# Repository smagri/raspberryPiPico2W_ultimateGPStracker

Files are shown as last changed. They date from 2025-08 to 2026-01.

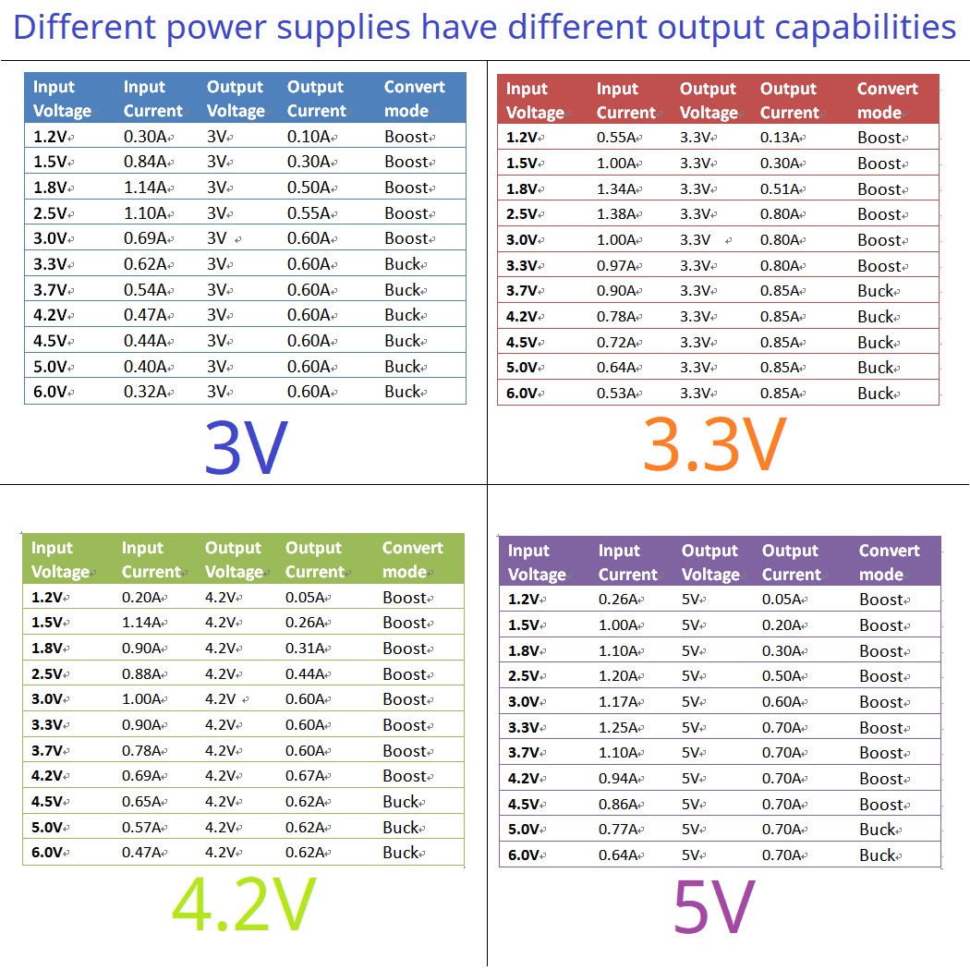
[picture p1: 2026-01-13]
images/ND0603PCbuckBoostSpecs.jpg

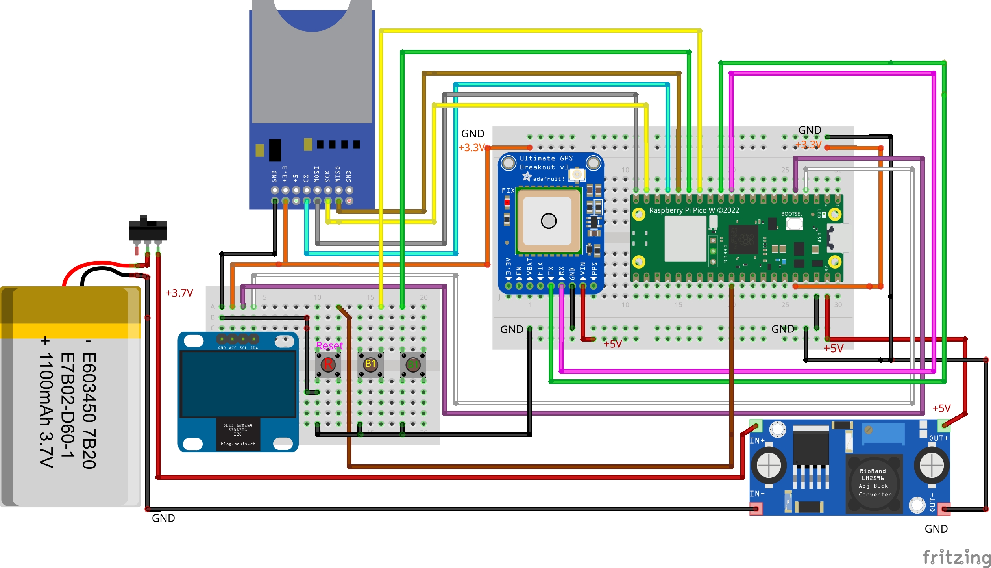
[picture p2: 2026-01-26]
images/circuitDiagram.fzz.3.jpg

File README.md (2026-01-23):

Project started 19jul2025.

This  project follows  Paul McWhorter  youtube videos  to build  a GPS
tracker with the Rasberry Pi Pico W.  However, I have used the Pi Pico
2 W and everything works well.   Note also that all .pdf documents are
in  ~/proj/paulMcWhorter/docs/ultimateGPStracker also,  but links  are
given below.

Bill of materials:
-----------------
Raspberry Pi Pico W: 
https://amzn.to/3FA4tqS

Adafruit Ultimate GPS version 3:
https://amzn.to/4jeRIjj

External Antenna (OPTIONAL) I would highly recommend this: 
https://amzn.to/4myFWTL

Button Battery For Quicker Fix: 
https://amzn.to/3FjoUbH

Breadvolt Power  Supply (OPTIONAL) I  would highly recommend  this for
when your project is finished:
https://amzn.to/4kuuJ50

Charging Cable (If You Don’t Have): 
https://amzn.to/3Z0EMGF

OLED SSD1306: 
https://amzn.to/43tFYUk

Soldering Iron: 
https://amzn.to/3HpZolw

Solder Practice Components:
https://amzn.to/4mNaEca

Extra Solder: 
https://amzn.to/4kuuDdE

Safety Glasses: 
https://amzn.to/4mwGMjR

Breadboard and Wires (If You Don’t Have): 
https://amzn.to/4kggv86

Hard boot of raspberry pi pico 2
--------------------------------

Hard boot, all hardware is reset:

Connect pin30==RUN momentarily to ground.  Any main.py in flash memory
starts executing immediately.

Or plug and unplug the USB cable.

Programming the raspberry Pi Pico 2:
-----------------------------------

Raspberry Pi Pico 2 W with RP2350, is the correct firmware file from:
https://www.raspberrypi.com/documentation/microcontrollers/micropython.html
mp_firmware_unofficial_latest.uf2

To flash firmware,  hold down bootsel button while  plugging in power,
then copy  .uf2 to  RP2350 mass  storage device  that appears  on your
computer.  If correctly flashed the  mass storage drive will dissapear
from your computer directory.

ls /dev/ttyACM0  should now  appear, so  select it  in thonny  and you
should get the miropython prompt.

Test with:
print("hello").

Why  use thonny  editor as  the default  editor for  rasberry pi  pico
-------------------------------------------------------------------------
projects:  I  use  emacs  for  editing  and  thonny  for  running  the
-------------------------------------------------------------------------
micropython scripts.
-------------------------------------------------------------------------

1.  Beginner-Friendly  Design:  Thonny is  specifically  designed  for
beginners in programming, especially  for Python. Its clean interface,
built-in debugger, and  minimal setup make it ideal for  new users and
education settings.

2.  Native Support  for MicroPython  The  Pico W  runs MicroPython,  a
lightweight version of Python for microcontrollers. Thonny has:

Built-in MicroPython support

A REPL (Read-Eval-Print Loop) interface to interact directly with the Pico

Automatic detection of MicroPython boards

This makes  it easy  to write,  upload, and  test code  on the  Pico W
without needing extra tools or command-line knowledge.

3. One-Click Installation & Setup
Setting up a Pico W with Thonny is simple:

Plug in the board (holding BOOTSEL)

Drag the firmware .uf2 file

Open Thonny, select the Pico interpreter (MicroPython on Raspberry Pi Pico)

Thonny handles the rest, including communication over USB serial.

4.  Thonny works  on Windows,  macOS,  and Linux  and is  lightweight,
requiring very few  resources. Perfect for use  on low-powered laptops
or in classrooms.

5. Official  Raspberry Pi Foundation Recommendation.  The Raspberry Pi
Foundation recommends Thonny  for Pico users in  its documentation and
tutorials  because  it aligns  with  their  goal of  making  computing
education accessible.

  * [ ] 
Alternatives Exist (for more anced users)
While Thonny is ideal for beginners, advanced users sometimes prefe:

VS Code (with the Pico-Go extension)

mpremote + rshell for CLI tools

PyCharm (with some setup)

Installing the ssd1306.py, the ssd1306 driver for the OLED
----------------------------------------------------------

Get the current version of the ssd1306 driver from the github repository:

From repository: https://github.com/micropython
https://github.com/micropython/micropython-lib/blob/master/micropython/drivers/display/ssd1306/ssd1306.py
In the directory:
https://github.com/micropython/micropython-lib/tree/master/micropython/drivers/display/ssd1306

Copy it into the directory where your main.py file is, in our case
ultimateGPStracker.py is our main.py.

File->Save As and SELECT 'Raspberry Pi Pico' (not 'This Computer') to
write this driver into the pico's filesystem.

Howto display on the ssd1306 OLED
---------------------------------
https://docs.micropython.org/en/latest/esp8266/tutorial/ssd1306.html

GPS - NMEA sentence information
-------------------------------
https://aprs.gids.nl/nmea/#rmc

CD-PA1616S GPS patch antenna module, ie for adafruit ultimate GPS version 3
---------------------------------------------------------------------------
Data Sheet V.04
---------------
https://cdn-shop.adafruit.com/product-files/746/CD+PA1616S+Datasheet.v03.pdf

Alternative method for calculating day and time(needs to be tested) in
----------------------------------------------------------------------
mycropython.
-----------
There is a function in the Pico that can do the heavy lifting for the
clock/calendar time offset, try this:

        utcDate = NMEAmain['GPRMC'].split(',')[9]
        myYear = int(utcDate[4:]) + 2000
        myMonth = int(utcDate[2:4])
        myDay = int(utcDate[0:2])

        utcTime = NMEAmain['GPGGA'].split(',')[1]
        myHours = int(utcTime[0:2])
        myMin = int(utcTime[2:4])
        mySec = int(utcTime[4:6])

        # Convert date/time to Epoch seconds, and add (/subtract) the offset in seconds
        myTimeDate = 
		time.mktime([myYear,myMonth,myDay,myHours,myMin,mySec,0,0]) + 3600 * utcCorrection
        
		# Convert Epoch time (now with the offset) back to date/time
        myYear,myMonth,myDay,myHours,myMin,mySec,myWday,myYday = time.gmtime(myTimeDate)

		# In some parts of the world, day and month are in reversed order.
		GPSdata['date'] = f'{myDay:2d}/{myMonth:02d}/{myYear:04d}' 
        GPSdata['time'] = f'{myHours:02d}:{myMin:02d}:{mySec:02d}'

Standard/summer time could be a flag that you set or reset manually,
during summertime you add an extra 3600 seconds to the Epoch time...

Thread yield, yield_thread() in readGPSdata() thread.
-----------------------------------------------------

We need to do this as there is a bug in the micropython implementation
on the  raspberry pi pico w  or pico 2  w hardware we are  using, when
doing threading.  See link to issue on the micropython github page.
https://github.com/micropython/micropython/issues/10621
https://github.com/micropython/micropython/issues/12698

PMTK command packets:
---------------------
https://cdn-shop.adafruit.com/datasheets/PMTK_A11.pdf

Power Up using Bread Volt
-------------------------
* 3.3V rail to OLED VCC
* 5.0 rail to pin39 - VSYS
* copy ultimateGPStracker.py to main.py, as on power-up pico runs
  main.py automaticly
* if thonny doesn't find main.py due to symlink of lu1 just load it
  from the command line:

  thonny ultimateGPStracker.py main.py

Resetting raspberry pi pico
---------------------------

Firstly, my  rasberry pi  pico 2 w  is plugged into  the USB  port, no
Bread Volt  attached.  Note it  is a pico  2 w not  a pico w.   A hard
reboot  mens the  microcontroller resets  completely. RAM  is cleared,
main.py runs again  from the start.  All peripherals,  UART, I2C, SPI,
GPIO, etc  reset to default  states.  USB serial sessions  are dropped
and reconnected.

Ways to do it:

Press the RESET button on the board. ie RUN pin30 to ground
momenterily.

Disconnect and reconnect the USB power.

Call machine.reset() in MicroPython (which triggers a full hardware
reset).

Thonny hanging on File->Save As main.py and mpremote hanging.
-----------------------------------------------------------------

So I  tried to  flash main.py  via thonny File->Save  As and  it hung.
Tried to kill main.py with mpremote and it hung also.  Consequently, I
had to  execute the following  commands on  the command line  to flash
main.py into the raspberry pi pico 2 w:

	Firstly Try to run this file and try again:
	-------------------------------------------
	* kill main with button2
	* ~smagri/bin/flush.mycropython.buffers

	Secondly now try ~smagri/bin/mpremote.sjm instead of mpremote here:
	(you can also use this to REMOVE ANY FILE FROM THE PICO):
	-------------------------------------------------------------------------------

* kill main with button2

* to get the python prompt and just connect to the serial port.
mpremote connect /dev/ttyACM0 

* NOTE: sometimes you need to press return to get the >>> REPL prompt.

>>> import os

>>> os.listdir(".") 
['main.py', 'ssd1306.py', 'ultimateGPStracker.log']

>>> os.remove('main.py')

>>> os.listdir(".") 
['ssd1306.py', 'ultimateGPStracker.log']
>>> 

*  Ctrl-X to get out of >>> REPL mode

*  Or Press the RESET button on the board. ie RUN pin30 to ground
   momenterily, to get out of >>> ie REPL mode.

NOTE:
Once you’re inside the MicroPython REPL (the >>> prompt on your Pico),
you’re  no  longer talking  to  your  computer’s filesystem  —  you’re
talking only to the Pico’s filesystem.

* unplug and replug in the usb cable - hard reboot.  Or Press the
  RESET button on the board. ie RUN pin30 to ground momenterily.

* do an mpremote command:
  mpremote connect /dev/ttyACM0 fs cp main.py :

	Thirdly Try:
	------------
	
You will need these:
* pip install mpremote
* wget https://datasheets.raspberrypi.com/soft/flash_nuke.uf2

* With boot sel pressed plug in usb cable.
* OR 
* Put the pico in bootloader mode, mpremote connect /dev/ttyACM0 bootloader

  Now RP2350,that is pico will appear as a drive on your PC and you
  can copy things to it.
  
* cp flash_nuke.uf2 /media/.../RP2350/ ,to clear mycropython from pico
* cp mp_firmware_unofficial_latest.uf2 /media/.../RP2350/ ,to copy
  back mycropython.
* mpremote connect /dev/ttyACM0 fs ls ,should be empty

* mpremote  connect /dev/ttyACM0 fs  cp main.py ssd1306.py :  ,to copy
  back your main file, cp source to destination, : is the pico.
  
* Then your main.py is flashed to your pico.  mpremote connect
  /dev/ttyACM0 fs ls ,should show main.py and ssd1306.py to be there.

However, this still didn't solve my problem with a hard reboot running
my code.  So then  I had to modify my code to fix  my bug.  Remember a
soft reboot,  running code from  thonny, the GPS receiver  had already
been  running  and my  code  worked.   So  I  guessed that  putting  a
time.sleep(10) in my main.py, after importing the libraries and before
any other  code, on a hard  reboot would give the  GPS receiver enough
time to settle before running any code.  Thus on a hard reboot my code
now worked.  Also, I was able to  unplug the pico from usb and use the
Bread Volt and everything worked fine.

Obviously, this is a hack but perhaps it would be fixed by polling the
GPS receiver via some register to see if it is actually up and running
before executing any  code.  Also, perhaps others are  not seeing this
problem as I am using a pico 2 w  not a pico w so the pico 2 is faster
so  perhaps is  not leaving  the GPS  receiver enough  time to  settle
properly before executing code.

Firmware(see firmware directory):
---------------------------------
flash_nuke.uf2

This is  a special erase utility  provided by Raspberry Pi.   When you
copy this  to your Pico  in BOOTSEL mode,  it erases the  entire flash
memory of the microcontroller.  Afterward,  the board will appear as a
blank device, and you can  install a fresh MicroPython, CircuitPython,
or C/C++  firmware.  It doesn’t  leave anything  useful to run  – it’s
purely for “factory reset” of the flash.

mp_firmware_unofficial_latest.uf2

This is  a firmware image  containing MicroPython (MP  = MicroPython).
"Unofficial"  means  it’s  not  from  the  Raspberry  Pi  foundation’s
official builds but  probably from a community  contributor or nightly
build.  Copying this  .uf2 onto the Pico in BOOTSEL  mode will install
MicroPython on the device.

After flashing, the Pico will reboot and expose a REPL (interactive
Python shell) over USB.

In short:

* .uf2 = a firmware update file format.
* flash_nuke.uf2 = erases the chip.
* mp_firmware_unofficial_latest.uf2 = installs MicroPython firmware.

Running standalone files on the pico 2 w:
-----------------------------------------

Remove all files off the pico, probably just main.py at it seems to be
special and runs itself regardless  what's in thonny or commandline as
a standalone script.

Delete via command line or via thonny.
main.py
ssd1306.py

cp standalone.py (eg dataLineRW2picoFlash) to pico.

Select standalone.py from the file view on the pico:
import standalone - to run the script

Note a double import doesn't work  till you get the micropython prompt
back with  a soft  reboot, ie  Ctrl-D, in  thonny or  the commandline.

Alternative to the soft reboot, as per chatGPT:

>>> import sys
>>> # remove from sys.modules if present
>>> if 'dataLineRW2picoFlash' in sys.modules:
...     del sys.modules['dataLineRW2picoFlash']
...
>>> # also remove the name from globals if present
>>> try:
...     del dataLineRW2picoFlash
... except NameError:
...     pass
>>> # now import again (this will execute the file)
>>> import dataLineRW2picoFlash

In short(put it in a script, like rerunStandaloneFile, cut and past):

import sys
del sys.modules['dataLineRW2picoFlash']
del dataLineRW2picoFlash
import dataLineRW2picoFlash

NOTE: this is  a valid namespace getter in mycropython,  may be useful
sometimes but  a Ctrl-D soft reboot  in thonny is the  easiet thing to
do, then do a run of the script on the pico:

>>> from dataLineRW2PicoFlash import *
Data written to log.txt
Raw data: 25.5,26.0,24.8
Parsed data: ['25.5', '26.0', '24.8']
>>> float(values[1])
26.0
>>> 

Python command line program to xfer logfiles/files flashed to the
-----------------------------------------------------------------
Pico W to PC.
-------------

Once the logfile has been created on the pico, ultimateGPStracker.log,
read       this       logfile        to       the       PC       using
xfer.ultimateGPStracker.log.Pico2PC.py.   However,  somtimes you  will
get blank  lines in your PC  logfile, ultimateGPStracker.log.OnPC.log.
I'm  not  sure  why  this  is so  yet,  needs  further  investigation.
If you have main.py running at all you will not be able to do the xfer
of the  logfile on the pico  to the PC as  the pico is talking  on the
serial port still.  So you must  somehow kill main.py and then run the
xfer script, xfer.ultimateGPStracker.log.Pico2PC.py. To do this, after
the system boots from a hard reboot press button2 to kill main.

The  problem turned  out that  the python  program with  prints in  it
worked and without prints it did not work.  I managed to work out that
the   UART   had   junk   data   in  it   before   my   main   program
xfer.ultimateGPStracker.log.Pico2PC.py started so I added some code to
flush the UART before the main part and end part of my code was run.

Converting logged csv of latitudes and longitudes to .kmz/.kml for
------------------------------------------------------------------
input to google earth.
----------------------

Use gpsvisualizer:
Goto: https://www.gpsvisualizer.com/map_input?form=googleearth

OR

sudo apt install gpsbabel
sudo apt install gpsbabelfe
select comma seperated variable input
select google earth variable output
gpsbabel -i csv -f ultimateGPStracker.log.OnPC.log -o kml -F output.kml

However, gpsbabelfe seems not as intuative as gpsvisualizer.

xfer.ultimateGPStracker.log.Pico2PC.py hangs:
--------------------------------------------

* make sure nothing is already controlling the serial port, like
  thonny or mpremote commandline tools.  Kill them both.

* kill main.py with the kill switch on button2

* run ~smagri/bin/flush.mycropython.buffers

* xfer.ultimateGPStracker.log.Pico2PC.py sometimes need to be run twice
  before it xfers the logfile, if it has hung.

		However, the real issue is that there isn't a little sleep after
		a serial object member function command.  I don't really know
		why this works, possibly some micropython bug.  Hence run:
		
		xfer.ultimateGPStracker.log.Pico2PC.withComments.py
		OR
		xfer.ultimateGPStracker.log.Pico2PC.withSleeps.py
		INSTEAD OF
		xfer.ultimateGPStracker.log.Pico2PC.py

xferPicoLog2PCcsv2kml.py
------------------------

This now replaces xfer.ultimateGPStracker.log.Pico2PC.py.

	It includes busy_wait_us(us) after each serialObj member function
    call.  Seems to be necessary for script not to hang.  Sweet point
    is 1us, ie busy_wait_us(1).  Making it smaller doesn't seem to
    make it run any faster.

Logging latitude and longitude to the sdcard:
-----------------
Get the current version of the ssd1306 driver from the github
-------------------------------------------------------------
repository:
----------

https://github.com/Lucvolders/MicroPython/blob/main/Libraries/SDcard/sdcard.py

Copy it  into the directory  where your main.py  file is, in  our case
ultimateGPStracker.py is our main.py.

File->Save As and SELECT 'Raspberry  Pi Pico' (not 'This Computer') to
write this driver into the pico's filesystem.

Using code(vscode) to access pico FS an manipulate files using
--------------------------------------------------------------
vscode(called code on linux).
-----------------------------
Install the MicroPython extension MicroPico.

Plug in pico to usb port.

You should see Pico Connected on bottom toolbar.

Select Toggle Mpy FS.

Ctr-Shift-P

Search for MicroPico commands.

Select MicoPico:Download project from pico.

This will let you edit, delete files, copy files to the pico...etc.

Use Ctr-Shif-P MicroPico:.....cmd to perform actions on the pico, like
run file on pico.

Writing data, ie latitude and longitude to the SDcard when logging
------------------------------------------------------------------------
travel.
-------------------------------------------------------------------------

While moving the  latitude and longitude is no longer  being logged on
the pico.  So we don't burn out the pico RAM write cycles.  We now log
this data  to an SDcard  interfaced to the  pico.  The data  is logged
into /sd/ultimateGPStrackerSDcard.log(via  Thonny or vscode)  with the
/sd  mount  point on  the  when  interfaced  to  the pico.   And  just
ultimateGPStrackerSDcard.log when mounting the  SDcard externally to a
PC.  At this stage it just continues appending data to this file.

At this stage there  is no python file you can run on  your PC to read
the logfile  data from the  SDcard when  interfaced to the  pico.  Use
xferSDcardLog2PCcsv2kml.py to  convert the  logfile to kml  format for
google   earth   and   such    systems,   but   the   SDcard   logfile
ultimateGPStrackerSDcard.log  must be  copied to  the PC  for this  to
work.

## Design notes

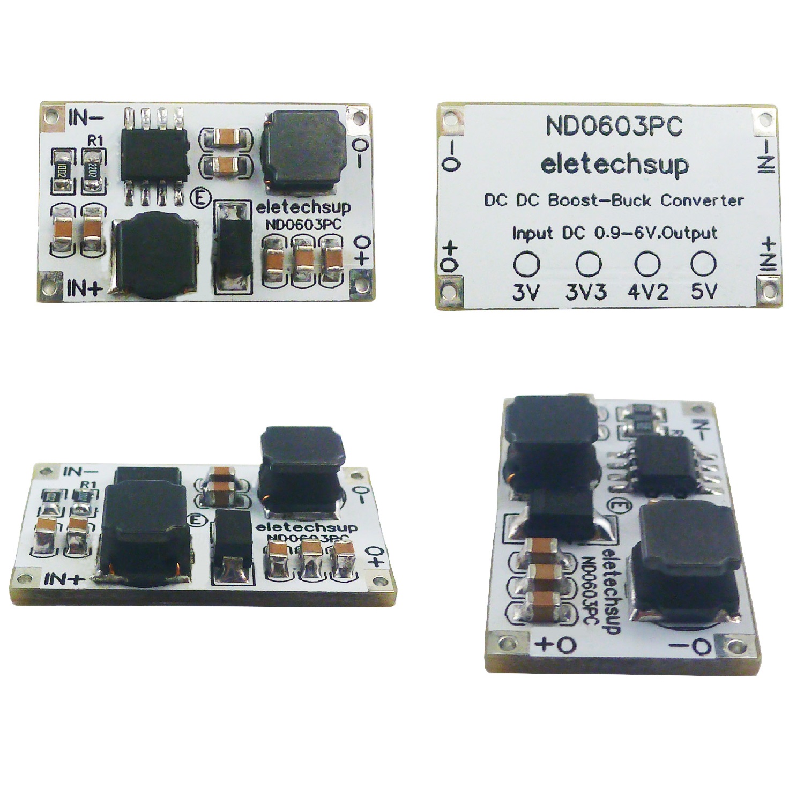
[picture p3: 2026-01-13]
images/ND0603PCimages.jpg

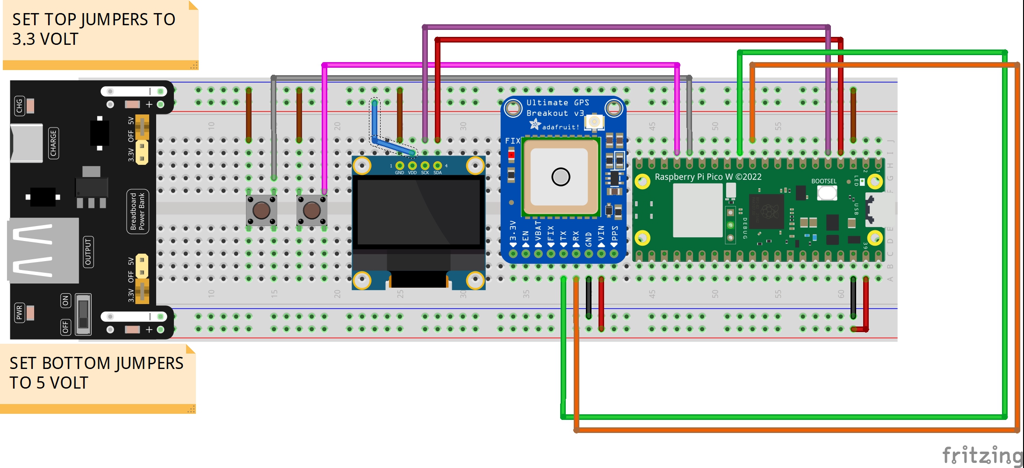
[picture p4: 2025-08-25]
images/gps-5_bb.jpg

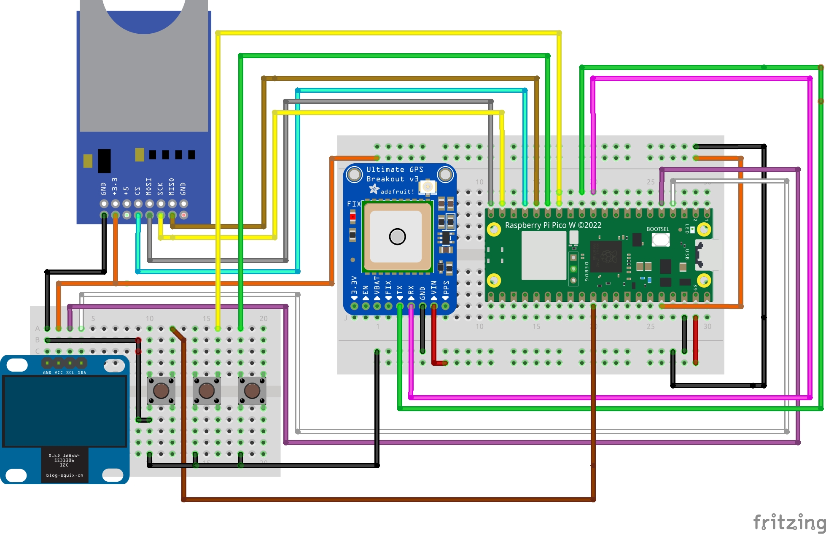
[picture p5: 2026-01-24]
images/circuitDiagram.fzz.jpg

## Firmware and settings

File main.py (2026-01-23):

# NOTE: heading is  azimuth, which is from north and clockwise to the angle

# GPGGA,010039.000,3346.5863,S,15058.1509,E,2,09,1.05,92.3,M,21.9,M,,*48

#       (1)UTCtime,(2)latitude,   (3)N/S   hemisphere,   (4)longitude,
#       (5)E/W  hemisphere, (6)do  we have  a fix(indicates  accuracy,
#       0=noFix,  1=normal   GPS  5-10m,  2=differential   fix  1-3m),
#       (7)number of  satellites used for  fix, (8)how diluted  is our
#       GPS  data.  The  lower the  number the  better, (9)our  actual
#       elevation in meters given the number of sattilites we have(you
#       need >5 for a good fix).

# The adafruit ultimate GPS version supports the GPS(USA), the
# original GPS system which is one of 5 GPS systems in use today.

# Satellite System	Supported?
#GPS (USA)	✅ Yes
#GLONASS (Russia)	❌ No
#Galileo (EU)	❌ No
#BeiDou (China)	❌ No
#QZSS (Japan)	❌ No

#
# $GPGSV,4,1,16,30,71,159,22,14,65,249,16,22,48,277,19,07,48,090,22*79

# (1)num  messages,  (2)message  number, (3)num  satellites  in  view,
# (4)satellite num fixed to, (5)elevation,  (6)azimuth is a bearing or
# measurment from north to east, (7)signal  strength in dB, 20-30 is a
# weak signal - btw 30-40 good signal -btw 40-50 is a very good signal
# then repeat from sattilite number, elevation, azimuth



# General info: 24  satellites in 6 different orbits,  they are evenly
# spaced above the earth, at  about 12,5000miles up.  Each one circles
# the globe twice  in 24hrs. Each sattilite transmits what  time it is
# and where I  am, time is based on atomic  clocks.  Remember it takes
# time to get  the signal, dist=speedOfLight*delay. With  dist you can
# draw a circle.  From 2 satellites you get you are on two points on a
# circle.  You need  3 sattilites to find your position  on the globe,
# where  all  three circles  intersect.   Your  GPS reciver  does  the
# triangulation.  However,  you may  be elevated  over the  earth, you
# need 4 sattilites  at a minimum to get elevation  of sea level/above
# the surface of the earth.  However,  how do we get time+error on our
# GPS  reciver,  this gives  us  one  more  unknown  we need  a  fifth
# satellite to get the error.  The  GPS reciver gets all data from the
# sattilites and then we can work out exactly where we are.


# Project 4:  video.  latitude is  pi/2 to  -pi/2, longitude is  PI to
# -PI, prime meridian at 0  degrees of latitude.  Counter clockwise is
# a +ve in longitude. +ve is north and east other directions are -ve.

# latitude: N/S 1st  two digits are degrees, rest  is decimal minutes.
# We need  to convert to  decimal degrees.
# longatude E/W 1st three  digits are degrees, rest is decimal minutes.


# OLED display is an Hosyond 0.96  Inch OLED I2C Display Module 128x64
# Pixel  Screen IIC  Serial Mini  Self-Luminous Board  Compatible With
# Arduino Raspberry  PI (Blue and Yellow).   On the back of  the board
# there is  an address selector, in  this case a resistor  for address
# 0x3C.  However,  it can be  configured for address 0x30  also.  Note
# that each  character displayed on  the screen  is 8 pixels  wide and
# high.   That means  you can  display upto  16 charachters  along the
# screen and 8 lines down the screen.

# circuit diagram https://toptechboy.com/wp-content/uploads/2025/06/gps-OLED.jpg
#
# Since pico is a 3.3V device 3.3V needs to be used to power I2C
# devices.

from machine import SPI, Pin, I2C, UART, reset
import time
import _thread
from ssd1306 import SSD1306_I2C
import math
import sys
import os  # Import os module for file system operations
import sdcard


# Create  global symbols  immediately, before  any main()  or thread()
# gets  to run.   Why: MicroPython  threads can  run immediately  when
# started, and global variables may not exist yet if they are assigned
# later in main().

# Otherwise, you get intermittent errors like:

# NameError: name 'keepRunning' isn't defined
# NameError: name 'GPS' isn't defined

keepRunning = False      
GPS = None
NMEAdata = {}
dataLock = None



def logging2sdcard():


    curLatitude = GPSdata['latitudeDecimalDegrees']
    curLongitude = GPSdata['longitudeDecimalDegrees']

    appendLine_strLine = str(curLatitude) + "," + str(curLongitude)
    sdcard_file.write(appendLine_strLine + '\n')

    # A write in Micropython is buffered. flush() and close() flush data.
    sdcard_file.flush()

    # Read this file from the sdcard
    # sdcard_file = open('/ultimateGPStrackerSDcard.log', 'r')
    # sdcardContents_line1 = sdcard_file.read()
    # sdcard_file.close()
    # print(sdcardContents_line1)

    time.sleep(0.3)

    return curLatitude, curLongitude



#time.sleep(10)
def logging2pico():

    # Logs latitude  and longitude values  as comma seperated  list on
    # seperate lines into a logfile on the raspberry pi pico w.

    # Note:  you  may be  concerned  about  the open/close  each  time
    # logging2pico() is called but really the overhead in this program
    # is running  python so it's no  big deal and probably  better for
    # program simplicity.

    # Note: the pico  has 2MB flash, 1MB for the  firmware and 1MB for
    # were you can store data.  So  be cognisant of how often you want
    # to log.

    try:
        # Open logfile in append mode ('a').  This will append to an
        # existing file or create it if it doesn't exist.  Using the
        # 'with' keyword lets the system handle when the file should
        # be closed.
        with open('ultimateGPStracker.log', 'a') as fileApicoFlash:  

            # Remember that  readGPSdata() thread runs to  get the raw
            # NMEA  sentences  into NMEAdata/NMEAmain  map/dictionary.
            # Then  parseAndProcessGPSdata()   populates  the  GPSdata
            # map/dictionary. GPSdata dictionary is global. 
            
            # Get the current latitude and longatude values.
            curLatitude = GPSdata['latitudeDecimalDegrees']
            curLongitude = GPSdata['longitudeDecimalDegrees']

            # Construct a CSV line string of current latitude and
            # longitude values.
            appendLineCSVstrLine = str(curLatitude) + "," + str(curLongitude)

            # fileApicoFlash.write() requires a string like "30.1,29.8,31.0"
            # Append the line with a newline
            fileApicoFlash.write(appendLineCSVstrLine + '\n')

            # paul here  adds: It forces  python to write its  data in
            # the RAM buffer to the  file.  Though 'with' block out of
            # scope should do this anyway  but if your program crashes
            # or the  pico resets  before the  with block  closes that
            # last line might never make it to the flash.
            fileApicoFlash.flush()
            time.sleep(0.1)  # sleep 0.1 seconds, 10th of a second, 100ms
            #time.sleep(30)
            
            #print("dbg: logging2pico: Appended Line is=", appendLineCSVstrLine)

        # 'with' keyword closes  the file now as it's block  is out of
        # scope.  The file is closed even if an exception occurs.
            
        # Confirm data was appended
        print("Appended new readings to ultimateGPStracker.log")  
    except OSError as e:
        # Handle errors like full flash
        print("Error appending to ultimateGPStracker.log:", e)

    return curLatitude, curLongitude



def radians2degrees(radians):

    # Note  that  latitude  and  longitude are  expressed  in  decimal
    # degrees on our ssd1306 OLED display.

    # can use python library math.radians(degrees)
    return (radians * 180 / math.pi)



def degrees2radians(decimalDegrees):

    # Note  that  latitude  and  longitude are  expressed  in  decimal
    # degrees on our  ssd1306 OLED display.  That is  the GPS reciever
    # outputs values in decimalDegrees.

    # can use python library math.degrees(radians)
    return (decimalDegrees * math.pi / 180)



def distanceBtw2PointsOnEarth(latitudeDecimalDegrees1,
                              longitudeDecimalDegrees1,
                              latitudeDecimalDegrees2,
                              longitudeDecimalDegrees2):

    # We need to use non-Euclidian geometry calculations as the earth is
    # roughly a sphere.  So we  move from one latitude,logitude value to
    # another in  a curved  manner.  When approximating  the earth  as a
    # sphere  even though  it is  not a  perfect sphere,  the errors  in
    # almost all applications would be trivial.

    # We need to  do our calutations in Radians so  to convert degrees
    # to radians, radians = degrees(2PI/360).

    # Radius of the earth is (m):
    R = 6371000

    # Great-circle distance (Haversine  formula) For global distances,
    # use the Haversine formula (non-Euclidean spherical geometry):

    # Calculate the included angle(central angle) theta:
    
    # Convert degrees to radians
    phi1 = degrees2radians(latitudeDecimalDegrees1)
    phi2 = degrees2radians(latitudeDecimalDegrees2)
    lamda1 = degrees2radians(longitudeDecimalDegrees1)
    lamda2 = degrees2radians(longitudeDecimalDegrees2)

    # Differences
    dphi = phi2 - phi1
    dlamda = lamda2 - lamda1

    # Haversine formula, takes in the curvature of the earth.
    a = math.sin(dphi/2)**2 + math.cos(phi1) * math.cos(phi2) * math.sin(dlamda/2)**2

    # we have the included angle(central angle)
    theta = 2 * math.asin(math.sqrt(a))
    #print("dbg: " + "Included Angle/Central angle (haversine formula):",
    #      theta, "radians")

    # distance between to points on earth, great circle distance, in m
    greatCircleDistance = (theta * R)
    GPSdata['distanceP1P2'] = round(greatCircleDistance, 2)

    # if you don't return a value python returns none
    
    # suppress jitter for very small distances
    minThreshold = 10
    if greatCircleDistance < minThreshold:
        GPSdata['distanceP1P2'] = 0
    
    return GPSdata['distanceP1P2']

    

def headingBtw2PointsOnEarth(latitudeDecimalDegrees1,
                             longitudeDecimalDegrees1,
                             latitudeDecimalDegrees2,
                             longitudeDecimalDegrees2):

    # if you don't return a value python returns None

    # The  instability   in  the  heading  values   comes  from  small
    # unstable distances, not from small  headings. You need to compute
    # the distance first, then suppress heading if distance < 10 m.
    minThreshold = 10
    distanceP1P2 = distanceBtw2PointsOnEarth(latitudeDecimalDegrees1,
                                             longitudeDecimalDegrees1,
                                             latitudeDecimalDegrees2,
                                             longitudeDecimalDegrees2)
    
    if distanceP1P2 < minThreshold:
        # heading value is unreliable
        GPSdata['headingP1P2'] = None
        return None
    
    # Initial bearing/heading (forward azimuth).  Heading is the angle
    # measured  from  North  cockwise   in  the  azimuth  or  logitude
    # direction.

    phi1 = degrees2radians(latitudeDecimalDegrees1)
    phi2 = degrees2radians(latitudeDecimalDegrees2)
    lamda1 = degrees2radians(longitudeDecimalDegrees1)
    lamda2 = degrees2radians(longitudeDecimalDegrees2)
    
    dlamda = lamda2 - lamda1

    # For a right angle triangle
    opposite = math.sin(dlamda) * math.cos(phi2)
    adjacent = math.cos(phi1) * math.sin(phi2) - math.sin(phi1) * math.cos(phi2) * math.cos(dlamda)

    # using atan2 means all the special cases of negative numbers are
    # dealt with due to the angle being in different quadrants.  It
    # returns an angle -π to +π radians (that’s -180° to +180°).
    headingRadians = math.atan2(opposite, adjacent)
    headingDecimalDegrees = radians2degrees(headingRadians)
    # Normalize 0–360 as could end up in the range -180deg to 180deg
    headingDecimalDegrees = (headingDecimalDegrees + 360.0) % 360.0

    GPSdata['headingP1P2'] = round(headingDecimalDegrees, 2)

    return GPSdata['headingP1P2']




def firstSunday(year, month):
    #"""Return the day (date) of the first Sunday for given month/year."""
    # Zeller’s congruence-like calculation
    # 0 = Saturday, 1 = Sunday, ...
    # Python's weekday(): Monday=0, Sunday=6
    from math import floor
    # Start at day 1
    import utime  # MicroPython time module

    # 1.   Build a  "time tuple"  for the  first day  of the  month at
    # 00:00:00.  utime.mktime()  expects a  tuple: (year,  month, day,
    # hour, min, sec, weekday, yearday)  The last two values (weekday,
    # yearday) can be  0 because mktime() recalculates  them.

    # A tuple  is an ordered  collection of  values.  It looks  like a
    # list, but it  uses round brackets () instead  of square brackets
    # [].Memory efficiency: Tuples use slightly less memory than lists
    # — useful in MicroPython on  small devices like the Pico.  Faster
    # lookups: Accessing elements in a tuple  can be a bit faster than
    # in a list.  Unlike a list,  a tuple is immutable → once created,
    # you cannot change its elements.


    
    # utime.mktime() Converts a "broken-down time" (a tuple with year,
    # month, day, hour, etc.) into a UNIX timestamp (an integer number
    # of seconds  since the epoch).   Epoch in MicroPython:  usually 1
    # Jan 2000 00:00:00  UTC (not 1970 like in  full Python), although
    # this can vary by port/board.

    t = utime.mktime((year, month, 1, 0, 0, 0, 0, 0))
    # tuple output is # Example output: (2025, 8, 25, 15, 42, 5, 0, 237)
    #
    # Meaning:
    # (year, month, day, hour, minute, second, weekday, yearday)

    # 2. Convert the timestamp back to a "localtime" tuple to find the weekday.
    # utime.localtime(t) → (year, month, day, hour, min, sec, weekday, yearday)
    # weekday: Monday=0, Tuesday=1, ..., Sunday=6
    weekday = utime.localtime(t)[6]  # 0=Monday ... 6=Sunday

    # 3. Work out how far the first Sunday is from day 1.
    # If weekday == 6 → day 1 is already Sunday → return 1.
    # Otherwise, shift forward until the next Sunday.
    #
    # Formula: 1 + ((6 - weekday) % 7)
    #   - (6 - weekday) → how many days to "jump" to reach Sunday
    #   - % 7 makes sure it wraps around correctly (e.g. if already Sunday, jump = 0)
    #   - +1 because we start counting from day 1
    return 1 + ((6 - weekday) % 7)  # find first Sunday



def sydneyAutoCalcUTCoffset(year, month, day, hour):
    # Determine the current correct UTC offset for Sydney Australia.

    #utcOffset = 11  # AEDT
    #utcOffset = 10  # AEST
    
    # When Does DST Start and End in Sydney Australia?

    # Sydney Daylight Saving Rules (as of 2025):
    
    # Starts: First Sunday in October(10th month of year)—at 2:00 am
    # AEST, clocks spring forward to 3:00 am AEDT. utCoffset = 11

    # Ends: First Sunday in April(4th month of year)—at 3:00 am AEDT,
    # clocks fall back to 2:00 am AEST, giving you an extra hour.
    # utcOffset = 10

    # UTC offset for Sydney based on the current date using the
    # known DST rules.

    # DST starts: first Sunday in October(10th month of year)
    start_day = firstSunday(year, 10)
    # DST ends: first Sunday in April(4th month of year)
    end_day = firstSunday(year, 4)

    # --- October case: DST starts on first Sunday at 2:00am ---
    if month == 10:
        if day > start_day or (day == start_day and hour >= 2):
            utcOffset = 11
        else:
            utcOffset = 10

    # --- April case: DST ends on first Sunday at 3:00am ---
    elif month == 4:
        if day < end_day or (day == end_day and hour < 3):
            utcOffset = 11
        else:
            utcOffset = 10

    # --- Other months ---
    elif month > 10 or month < 4:
        utcOffset = 11  # Between October and March (exclusive)
    else:
        utcOffset = 10  # Between April and September (exclusive)

    
    return utcOffset



def yield_thread():
    # yeild thread in micropython.  This call doesn't pause, it just
    # hands control back to the scheduler so the other threads or global
    # setting code can run.
    time.sleep_ms(0)
    # hakky way to do this is: time.sleep(10)



# start: Paul McHowter readGPSdata() thread - PRONE TO BUG/HEAP
# fragmentation and corruption ########################################

# This is the  reading NMEAdata thread.  NMEAdata comming  for the GPS
# module via  a uart.  We  put this  in a thread  as we don't  want to
# loose data while processing it.

def readGPSdataOrig():
    # hacky time.sleep(10) as this also yeilds the thread

    # We  need  to  do  this  as  there is  a  bug  in  the  micropython
    # implementation on the raspberry pi pico  w or pico 2 w hardware we
    # are using.  See  readme file for link to issue  on the micropython
    # github page.

    # Essentially,  this  readGPSdata()  thread may  be  getting  called
    # before the main thread or  some global initialisation.  Hence, the
    # globals required  for this thread,  like keepRunning and  GPS, may
    # not be defined  when it runs.  Hence, the program  will never read
    # data as say  keepRunning is not set yet.  This  will also cause an
    # exception intermittently.  yeald_thread()  forces the other thread
    # or global initialisation  to run first.  Note  that a time.sleep()
    # here will yield this thread also.
#    yield_thread()
    #time.sleep(10)

    print("Thread Running readGPSdata")
    #print("dbg: readGPSdata: keepRunning=",keepRunning)

    # global means use the variable values defined outside this function
    # at the global(module) level
    #global keepRunning, NMEAdata, GPS # NMEAdata is a dictionary, like a map in c++
    global NMEAdata # NMEAdata is a dictionary, like a map in c++

    global keepRunning
    global dataLock
    global GPS
    
    # Initialise the GPS NMEA strings
    GPGGA = ""
    GPGSA = ""
    GPRMC = ""
    GPVTG = ""

    # Wait until GPS is initialized
    while GPS is None and keepRunning:
        time.sleep(0.1)

        
    # do nothing if there is no data in the buffer
    while not GPS.any():
        time.sleep(0.1) # thread yeilds to avoid busy waits, though I
                        # think GPS.any() is non-blocking

    # print("GPS UART has data, starting read loop...")   
    # now we have data, read buffer till it's empty, the stale
    # data, this clears the buffer
    while GPS.any():
        junk=GPS.read()
        print(junk)
        
    myNMEA = "" # initialise the NMEA string read from uart

    while keepRunning:
        # we only read NMEA data when it's present in the buffer
        if GPS.any():
            # Read one byte at a time, ie one char at a time till
            # EOL(in the while keepRunning loop), and decode it
            # from a byte to a string using utf-8 codec(ASCII is a
            # subset of UTF-8)
            myChar=GPS.read(1).decode('utf-8')
            # supress line feed, so you can contiue to read accross
            ##print(myChar, end="")
            myNMEA+=myChar
            if myChar == '\n':
                # When EOL is reached strip the EOL char from myNMEA string.
                myNMEA = myNMEA.strip()
                # to see what NMEA data I am getting as initially we
                # weren't getting GPVTG data
                #print("dbg: readGPSdata, myNMEA=", myNMEA)
                # store the NMEAdata strings into variables

                # gets characters 1 to 5 in the current NMEA string
                # (it skips index 0 and stops reading at character number 5)
                if myNMEA[1:6] == "GPGGA":
                    GPGGA = myNMEA
                if myNMEA[1:6] == "GPGSA":
                    GPGSA = myNMEA
                if myNMEA[1:6] == "GPRMC":
                    GPRMC = myNMEA
                if myNMEA[1:6] == "GPVTG":
                    GPVTG = myNMEA

                # if _all_  the NMEA ata is  present populate the
                # dictionary  NMEAdata. ie  setup the  map between
                # key=type of NMEA string = string of data
                #
                if GPGGA != "" and GPGSA!="" and GPRMC!="" and GPVTG!="":
                    # we must do this within a lock as other
                    # threads may want to access the NMEAdata
                    # dictionary elements at the same time
                    dataLock.acquire()
                    NMEAdata = {
                        'GPGGA' : GPGGA,
                        'GPGSA' : GPGSA,
                        'GPRMC' : GPRMC,
                        'GPVTG' : GPVTG
                    }
                    dataLock.release()

                myNMEA = "" # reset to read the next NMEA data string
    print("Thread Terminated Cleanly")  
# end: readGPSdataOrig() thread - PRONE TO BUG/HEAP fragmentation and corruption
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

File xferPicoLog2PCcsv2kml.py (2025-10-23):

#!/usr/bin/env python3

# Transfer  Pico W  2  logfile from  pico to  PC.   Then convert  this
# logfile to kml format for googleEarth and other such systems.

# Firstly:

###############################################################################
# Python command line program to xfer logfiles/files flashed to the
# Pico W to PC.
#
###############################################################################


# This  file sleeps  after  serial object  commands this  consistantly
# makes the script work.  While xfer.ultimateGPStracker.log.Pico2PC.py
# hangs.

# To be able to run this file  you must have sole access to the serial
# port.   Thus you  have to  kill main.py  on the  pico and  make sure
# thonny is  not connected to  the pico  also.  Connect thonny  to the
# python interpreter  to run the  script. Or  kill thonny and  run the
# script on  the command line.   Note the  first line of  this program
# allows you to run the script on the command line.

# NOTE: also  that a print()(just like  a small sleep) or  an explicit
# small sleep like time.sleeo(0.1)(100ms)  seems to be reaquired after
# each method for the serial  object, serialObj handle.  Otherwise the
# program will hang after vaious commands.

import serial
import time
import sys


serialPort= "/dev/ttyACM0"
baudRate = 115200 # for the pico it dosen't seem you can change this baudRate


# Open serial port connection to the pico.

# If this script doesn't get a response from the pico within 5 seconds
# it times out  and continues with the program,  hence timout=5.  Here
# serialObj  is  the  handle  for  our  serial  port.   For  instance,
# readline() operation  will wait  at most 5  seconds for  data before
# giving up.
try:
    serialObj = serial.Serial(serialPort, baudRate, timeout=5)
    time.sleep(1)
except serial.SerialException as e:
    sys.exit(f"Error opening port: {e}")
    

# To clear micropython UART buffer before the rest of my python script
# runs.  Otherwise readline()'s were out of sink.

# Fulsh the micropython UART buffer on the Pico W to PC.

# To be able to run this file  you must have sole access to the serial
# port.   Thus you  have to  kill main.py  on the  pico with  the kill
# switch and  make sure thonny is  not connected to the  pico also, or
# mpremote.  Killing main.py with the  kill switch I think still dumps
# corrupted data into the buffers.
serialObj.write(b"print(\"Input Buffer FLUSH\")\r\n")
serialObj.write(b"print(\"Output Buffer FLUSH\")\r\n")
while True:
    flushLine = serialObj.readline().decode("utf-8").strip()
    print("Waiting for ready, flushLine=", flushLine)
    if flushLine == "Output Buffer FLUSH":
        print("Flushed UART,", flushLine)
        break



# The pico is really the system that xfers the data to this python
# script running on the PC.  So we need to send commands to the pico
# as follows.

# An example of opening the pico logfile and reading the echoed
# response:

# Send bytes,  b, to  the pico,  open the  log file  on the  pico with
# handle filePicoHandle.   'with' keyword  handled opening  an closing
# the file  in our last  lession but here  because we are  running two
# machines, the  pico and the PC.   CR and LF are  required instead of
# doing it manually.

# \r\n are  required by  MicoPython REPL  on the  pico. \r  is carrige
# return and  \n is linfeed/newline.   So together \r\n is  a standard
# EOL sequence used in many communication protocols, especially serial
# terminals.

# The MicroPython REPL(mycropython running on the pico essentially) is
# the interactive prompt that lets you talk directly to a board (like
# the Raspberry Pi Pico or ESP32) running MicroPython. >>> is the REPL
# prompt, waiting for your python code.

# REPL stands for Read–Eval–Print Loop:
# Read → It reads what you type in (a Python command).
# Eval → It evaluates (executes) that command on the microcontroller.
# Print → It prints the result back to you.
#Loop → Then it waits for the next command.

# .write()  method expects  raw bytes  to send  over the  serial port.
# Computers  and microcontrollers  communicate  via  bytes not  python
# string objects.
serialObj.write(b"filePicoHandle=open('ultimateGPStracker.log','r')\r\n")
time.sleep(0.1)

# After  the pico  recived the  write() command  it returns/echos  the
# command back to the PC, so we can read it in.

#.decode('utf-8') converts the bytes received from serial port into a
# string.  So, Latitude,Longitude becomes "Latitude,Longitude"

# .strip() removes and leading and trailing whitespace charcters from
# the string, including \r\n
picoCmdResultLine = serialObj.readline().decode('utf-8').strip()
#print("Write to open file succeeded echoed line is= ", picoCmdResultLine)
time.sleep(0.1)

# Reading from logfile logfile on the pico to logfile on the PC:
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

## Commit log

2025-07-29 Completed ultimateGpsTracker.py but running gives an error.
    [ultimateGPStracker.py]
2025-08-01 Implemented fix in hardware of Adafruit Ultimate GPS tracker 3 to also include output of GPVTG NMEA strings.
    [ultimateGPStracker.py]
2025-08-02 Ultimate GPS Tracker Project 8: Parse GPS NMEA Sentences Using the Pi Pico W COMPLETED.
    https://www.youtube.com/watch?v=CilrRAswads&list=PLGs0VKk2DiYzyi_Y34-txIUA17hu4KnFT&index=10
2025-08-05 Fixed display artifacts on boarder of ssd1306 OLED.
    [ultimateGPStracker.py]
2025-08-06 Printing out raw date and time to serial console and sdd1306 OLED.
    However, there is yet no compensation for:
    * clock rolling from one day to the next, for positive UTC correction time.
    * clock rollover for negative UTC correction times.
    * calendar rollover at the end of the month, and the end of the year.
    [ultimateGPStracker.py]
2025-08-11 Added trueAltitue calculations.
    Magnetic Variation and Magnetic Variation Direction fail due to not
    being in the GPPMC string of the adafruit ultimategpstracker module.
    Shrunk display output so as to fit more values in.
    [ultimateGPStracker.py]
2025-08-12 Added comments for Magnetic Variation and Magnetic Variation Direction. The difference between the magnetic north of a compass and true north at the north pole.
2025-08-14 Added button on GPIO pin 12(yellow) to toggle between the screens.
    Ultimate GPS tracker upto project 11 done.
2025-08-15 yield_thread() function added to beginning of readGPSdata() thread. This call doesn't pause, it just hands control back to the scheduler so the other threads or global setting code can run. Otherwise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
    [ultimateGPStracker.py]
2025-08-18 Fixed GPS.write() that turns on the NMEA sentences to just the minimum number of NMEA sentences we use.
    GPS.write(b"$PMTK314,0,1,1,1,1,0,0,0,0,0,0,0,0,0,0,0,0,0,0*28\r\n")
    [ultimateGPStracker.py]
2025-08-20 Added main.py, a copy of ultimateGPStracker.py, and loaded into the raspberry pi pico 2 w(File->Save as - select pico). On powerup the pico runs main.py automatically.
    Added some comments to the readme.md for powerup of the Bread Volt.
    Circuit with Bread Volt attached not tested yet as Bread Volt still
    charging.
2025-08-22 Added docs directory.
    Added tools for nucking the pico 2 w(flash_nuke.uf2), ie deleting
    micropython and anything else on it.
    Added hack in main.py to give ultimate GPS tracker time to start and
    settle properly. Now main code works off soft(via Thonny) or hard
    boot(Thonny closed and unplug and replug the usb cable).
2025-08-25 Added automatic calculation of utcOffest for Sydney given 2025 DST rules.
    Works on pico so we are uptodate with ultimate GPS tracker project 12
    in the series of videos from Paul McWhorter.
    Some documentation added and updated.
2025-08-31 Testing calculation of distance between and the heading on the earth from one point to the another. Test example used was values of Melbourne, point1 to Sydney, point2. Checked results with google ea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
    Project13 complete.
2025-08-31 Copied ultimateGPStracker.py to main.py, tested, all is good. Thonny Save->As doesn't really work as expected.
    This is the proper final version of Project13, previous commit did not
    have the correct main.py flashed to the pico.
    [main.py]
2025-09-04 The code now waits for an acknowledgement responce to the GPS command sent to it. It also sends the GPS command out multiple times if it doesn't get an ack responce within a particular timeout value,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
    [main.py, ultimateGPStracker.py]
2025-09-08 Using our Haversine formula as a previous commit to determine distance between two points and heading. However, this time ask the user once for a point1 and point2 latitudes and longitudes.
    I put in paulsPropertyP1 and paulspropertyP2 and the answer is
    correct. As Sydney<->Melbourne was in previous commit.
    Project14 done.
    [ultimateGPStracker.py]
2025-09-10 Project 15: Measure Distance and Heading btw two GPS locations.
    Toggle pages with button1 to see data.
2025-09-17 Project 15: Measure Distance and Heading btw two GPS locations, distance and heading apper correct.
    However, requires 2 button presses to display distance and heading.
    [main.py, ultimateGPStracker.py]
2025-09-21 Project 15: Measure Distance and Heading btw two GPS locations, distance and heading appear correct. Also, button double press shows correct output.
    Some cleaning of documentation.
    [ultimateGPStracker.py]
2025-09-21 Project15: Page1 and Page2 details match to google earth within a small margin of error.
    Front Gate, P1, to Next Property, P2, variables calculated:
    GPS unit: GoogleEarth
    Latitude=-33.77644 33 36 35S identical
    Logitude=150.9691 150 58 08E identical
    TrueAltitude=71.1m 79.69m
    GPSAltitude=92.9m
    DistanceP1toP2~110m 111m
    Heading 86/264 82.49/261.72
    Fixed display of 'Wait to Fix' on OLED
    Some cleanup of files.
    [main.py, ultimateGPStracker.py]
2025-09-22 Ultimate GPS Tracker Project 16: Master Data Logging on the Raspberry Pi PIco W
    Implemented write to log.txt/log file on the pico from script and
    worked out howto rerun the script multiple times.
2025-09-22 Ultimate GPS Tracker Project 16: Master Data Logging on the Raspberry Pi PIco W
    Added some comments to dataLineRW2picoFlash.py.
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2025-09-24 Project16: Write and Read multiple lines to/from a logfile on the pico flash memory.
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2025-09-28 Project17: Write logfile from the pico flash to the PC logfile.
    Created a ultimateGPStracker.wrks.py as I'm paranoid of using
    branches.
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2025-09-29 Project17 Homework: display on ssd1306 OLED logging status and instructions when button2 is pressed.
2025-09-30 Project17 Homework: Homework done, that is write Latitude and Longatude to logfile on the pico as CSV.
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2025-09-30 Project17: Program to xfer logfile on pico to the PC written. But I don't quite understand it so probably requires different more explicit comments to be added.
2025-10-02 Project17: Program to xfer logfile on pico to the PC written and now commented sufficiently.
2025-10-03 Project17&18: Created a logfile outside as cvs latitude and longitude, converted to .klz/.klm, correct path in google earth.
    xfer file from pico to PC still does not work.
    [main.py, ultimateGPStracker.py, xfer.ultimateGPStracker.log.Pico2PC.py]
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2025-10-04 Project17: add README comments about corrupted UART data at start of xfer logfile from pico to PC .py script.
2025-10-06 Fixed: def sydneyAutoCalcUTCoffset(year, month, day, hour):
    [ultimateGPStracker.py]
2025-10-09 Project19: Button1 still works as expected. When button2 is pressed and then 5 seconds elapse we go into logging mode as required. Pressing button2 before 5 seconds does not kill main.py as required 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
2025-10-15 Project19: Finished. Logging data at precicly every loggingInterval seconds. Had broken it between this commit and some changes after.
    [main.py, ultimateGPStracker.py]
2025-10-15 Project19: Logging data at precicly every loggingInterval tested with main.py on pico. xfer.ultimateGPStracker.log.Pico2PC.py also works but sometimes you have to run it twice.
2025-10-17 xferPicoLog2PCcsv2kml.py transfers pico logfile to PC logfile which is then converted to a kml file, for googleEarth and such systems.
2025-10-29 Some improved documentation in README.md
    Cleaned up directroy.
    Shortened name of xfer pico log file to PC kml file.
    [xfer.ultimateGPStracker.log.Pico2PC.py]
2025-10-29 Added vscode directories from testing directory and tested that I could copy main.py to the pico.
2026-01-13 Logging latitude and longitude to the pico removed.
    Now logging latitude and longitude to file on the SDcard. This occurs
    once then fails. SDCard init is OK.
2026-01-14 Writing latitude and longitude to a logfile on the sdcard working.
    File on sdcard is only opened and closed once. sdcard is only mounted
    and unmounted once.
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2026-01-15 Cleaned up some unnecessary directories.
    Removed superfluous comments in main.c/ultimateGPStracker.py.
    Added to README.md howto use vscode(called code in linux) to access
    pico filesystem.
2026-01-15 First pass at reading lines from the sdcard logfile and writing them to a PC logfile, currently in xferSDcardLog2PCcsv2kml.py. WIP(Work In Progress), ie not tested yet.
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2026-01-19 Waiting for fix when disconnecting antenna works but not consistantly. But when buttons pressed(one and two it doesn't also, WIP.
    [xferSDcardLog2PCcsv2kml.py]
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2026-01-22 Hangging after button1 pressed fixed. Now we log to the SDcard and do all of ultimateGPStracker project20 properly.
    Cleaned up files and directories.
    [main.py, ultimateGPStracker.py]
2026-01-24 Created Fritzing circuit diagram.
    Made logfile of neighborhood run, ultimateGPStrackerSDcard.log.neighborhood.log.
    [ultimateGPStrackerBreadboardLayout.fzz]
2026-01-26 Updated fritzing circuit diagram.
    [ultimateGPStrackerBreadboardLayout.1.fzz, ultimateGPStrackerBreadboardLayout.2.fzz, ultimateGPStrackerBreadboardLayout.fzz]
2026-01-26 Tided up circuit diagram in fritzing again.
    [ultimateGPStrackerBreadboardLayout.3.fzz]
2026-02-08 Circuit diagram update, in fritzing and .jpg image.
    [ultimateGPStrackerBreadboardLayout.3.fzz]
